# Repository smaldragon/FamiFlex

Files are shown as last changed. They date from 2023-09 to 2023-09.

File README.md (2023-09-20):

# FamiFlex

> Note: This project is currently in a prototype beta state, use at own risk

This is the repo for the FF1 (aka FamiFlex) famicom/famiclone homebrew mapper, more info is avaliable at:

https://smaldragon.github.io/blog/famiflex.html

Render of the PCB

* **kicad** - contains the original Kicad Files
* **python** - scripts to help with generating rom files for burning
* **gerbers** - `.zip` files for production with JLCPcb

## Changelog

### v0b

* Changed ROMS to smd PLCC sockets, to better fit cart shells
* Adjusted dimensions of PCB to better fit cart shells

### v0a

Initial Version

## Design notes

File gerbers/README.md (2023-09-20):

Pre-prepared .zip files ready for production via JLCPCB, for the best results choose the following options:

* 1.2mm PCB Thickness
+ ENIG surface finish
* Gold Fingers
* Specify a location for Order Number

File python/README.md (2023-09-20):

Hacky prototype python scripts for quickly converting a .nes file into binary files to write to ROM. Should generate the following:

* prg.65x - 512Kb file, holds PRG data
* chr.65x - 512Kb file, holds CHR data (only generated if the mapper uses CHR rom)

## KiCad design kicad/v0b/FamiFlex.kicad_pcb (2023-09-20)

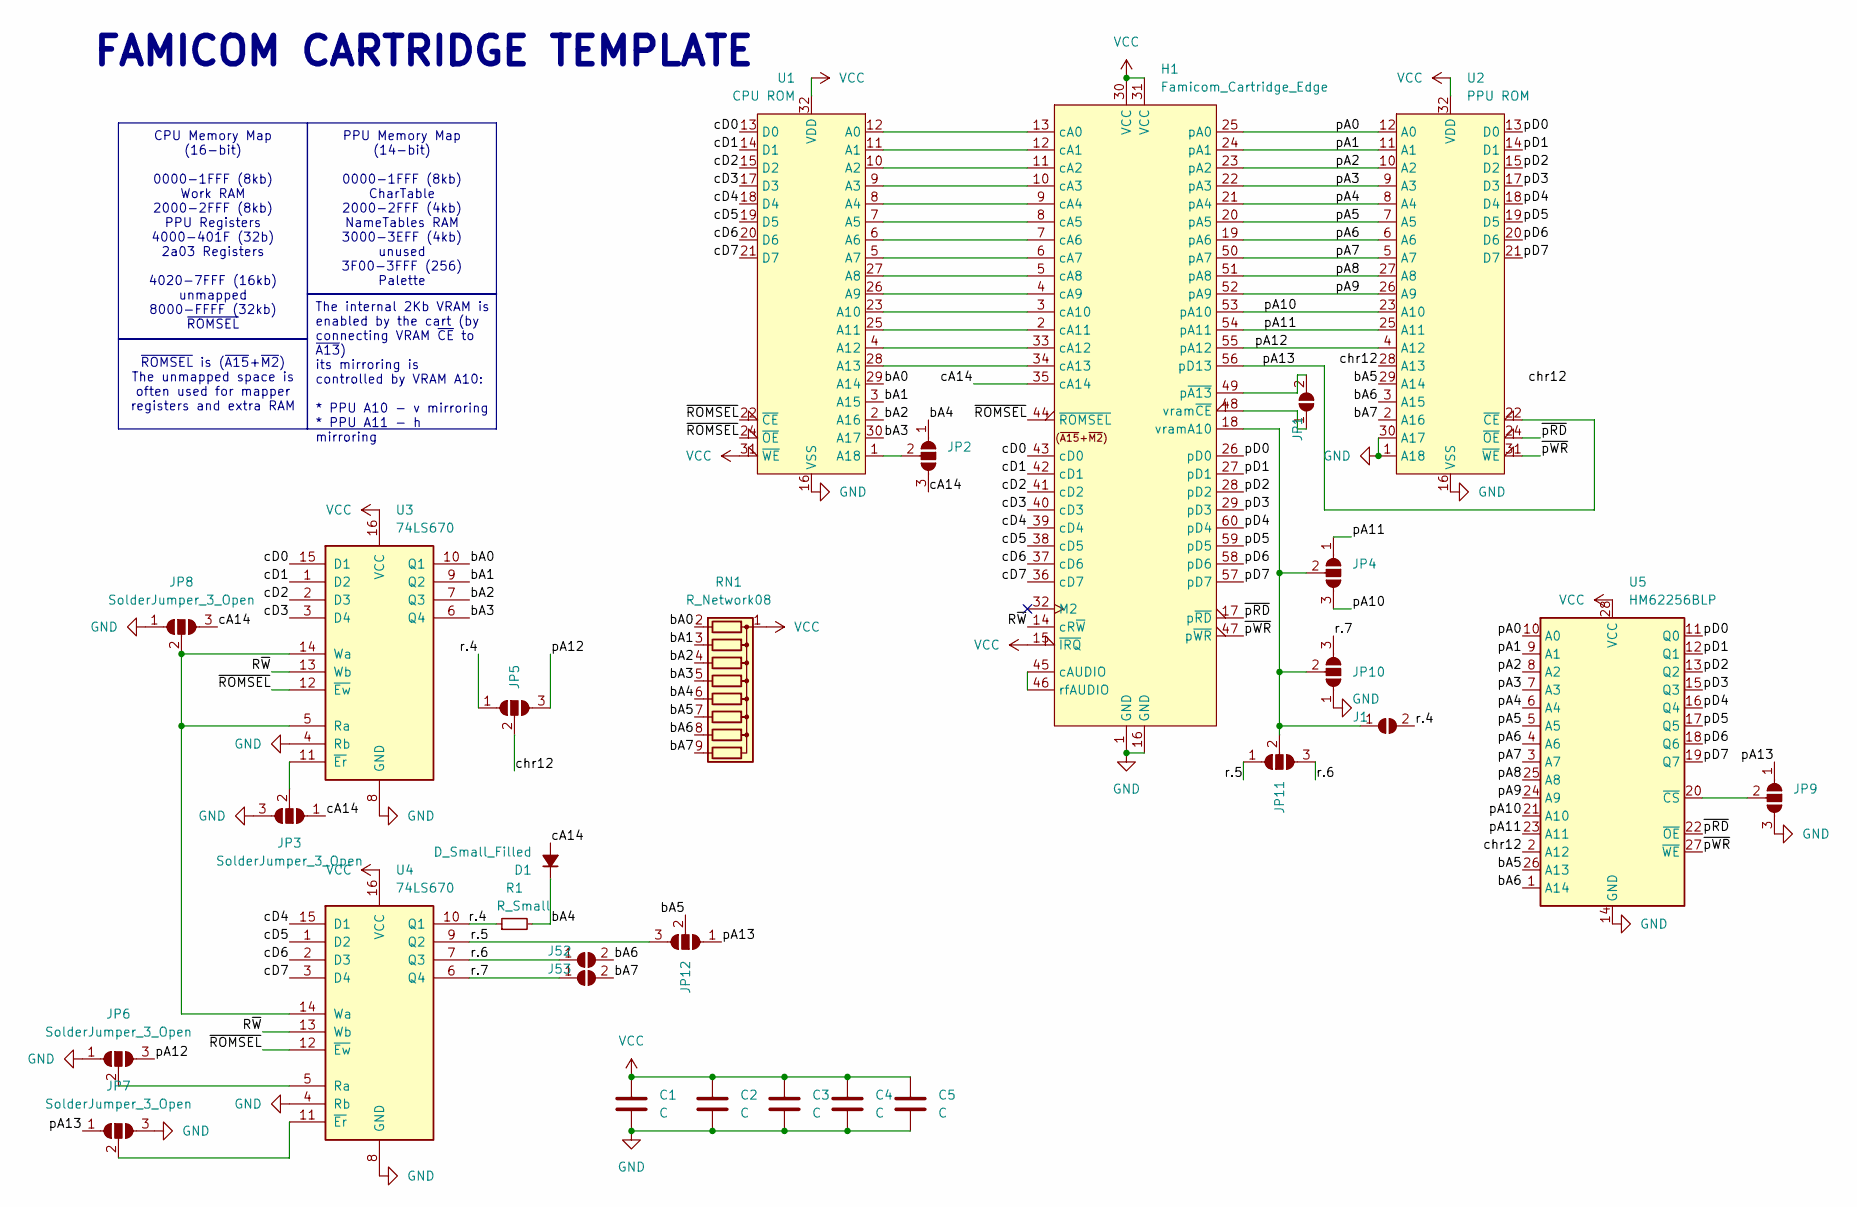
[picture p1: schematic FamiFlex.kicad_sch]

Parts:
C1, C2, C3, C4, C5: C; C_0805_2012Metric_Pad1.18x1.45mm_HandSolder
D1: D_Small_Filled; D_DO-41_SOD81_P2.54mm_Vertical_KathodeUp
H1: Famicom_Cartridge_Edge; Famicom Cartridge Edge Connector (long legs)
J1, J52, J53: SolderJumper_2_Open; SolderJumper-2_P1.3mm_Open_RoundedPad1.0x1.5mm
JP1: SolderJumper_2_Open; SolderJumper-2_P1.3mm_Open_RoundedPad1.0x1.5mm
JP2, JP3, JP4, JP5, JP6, JP7, JP8, JP9, JP10, JP11, JP12: SolderJumper_3_Open; SolderJumper-3_P1.3mm_Open_RoundedPad1.0x1.5mm
R1: R_Small; R_0805_2012Metric_Pad1.15x1.40mm_HandSolder
RN1: R_Network08; R_Array_SIP9
U1: CPU ROM; PLCC-32_SMD-Socket
U2: PPU ROM; PLCC-32_SMD-Socket
U3, U4: 74LS670; DIP-16_W7.62mm_Socket
U5: HM62256BLP; DIP-28_W15.24mm_Socket

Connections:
/R~W: H1.14 (cR~W), U3.13 (Wb), U4.13 (Wb)
/bA0: RN1.2 (R1), U1.29 (A14), U3.10 (Q1)
/bA1: RN1.3 (R2), U1.3 (A15), U3.9 (Q2)
/bA2: RN1.4 (R3), U1.2 (A16), U3.7 (Q3)
/bA3: RN1.5 (R4), U1.30 (A17), U3.6 (Q4)
/bA4: D1.1 (K), JP2.1 (A), R1.2, RN1.6 (R5)
/bA5: JP12.2 (C), RN1.7 (R6), U2.29 (A14), U5.26 (A13)
/bA6: J52.2 (B), RN1.8 (R7), U2.3 (A15), U5.1 (A14)
/bA7: J53.2 (B), RN1.9 (R8), U2.2 (A16)
/cA14: D1.2 (A), H1.35 (cA14), JP2.3 (B), JP3.1 (A), JP8.3 (B)
/cD0: H1.43 (cD0), U1.13 (D0), U3.15 (D1)
/cD1: H1.42 (cD1), U1.14 (D1), U3.1 (D2)
/cD2: H1.41 (cD2), U1.15 (D2), U3.2 (D3)
/cD3: H1.40 (cD3), U1.17 (D3), U3.3 (D4)
/cD4: H1.39 (cD4), U1.18 (D4), U4.15 (D1)
/cD5: H1.38 (cD5), U1.19 (D5), U4.1 (D2)
/cD6: H1.37 (cD6), U1.20 (D6), U4.2 (D3)
/cD7: H1.36 (cD7), U1.21 (D7), U4.3 (D4)
/chr12: JP5.2 (C), U2.28 (A13), U5.2 (A12)
/pA0: H1.25 (pA0), U2.12 (A0), U5.10 (A0)
/pA1: H1.24 (pA1), U2.11 (A1), U5.9 (A1)
/pA2: H1.23 (pA2), U2.10 (A2), U5.8 (A2)
/pA3: H1.22 (pA3), U2.9 (A3), U5.7 (A3)
/pA4: H1.21 (pA4), U2.8 (A4), U5.6 (A4)
/pA5: H1.20 (pA5), U2.7 (A5), U5.5 (A5)
/pA6: H1.19 (pA6), U2.6 (A6), U5.4 (A6)
/pA7: H1.50 (pA7), U2.5 (A7), U5.3 (A7)
/pA8: H1.51 (pA8), U2.27 (A8), U5.25 (A8)
/pA9: H1.52 (pA9), U2.26 (A9), U5.24 (A9)
/pA10: H1.53 (pA10), JP4.3 (B), U2.23 (A10), U5.21 (A10)
/pA11: H1.54 (pA11), JP4.1 (A), U2.25 (A11), U5.23 (A11)
/pA12: H1.55 (pA12), JP5.3 (B), JP6.3 (B), U2.4 (A12)
/pA13: H1.56 (pD13), JP7.1 (A), JP9.1 (A), JP12.1 (A), U2.22 (~CE)
/pD0: H1.26 (pD0), U2.13 (D0), U5.11 (Q0)
/pD1: H1.27 (pD1), U2.14 (D1), U5.12 (Q1)
/pD2: H1.28 (pD2), U2.15 (D2), U5.13 (Q2)
/pD3: H1.29 (pD3), U2.17 (D3), U5.15 (Q3)
/pD4: H1.60 (pD4), U2.18 (D4), U5.16 (Q4)
/pD5: H1.59 (pD5), U2.19 (D5), U5.17 (Q5)
/pD6: H1.58 (pD6), U2.20 (D6), U5.18 (Q6)
/pD7: H1.57 (pD7), U2.21 (D7), U5.19 (Q7)
/r.4: J1.2 (B), JP5.1 (A), R1.1, U4.10 (Q1)
/r.5: JP11.1 (A), JP12.3 (B), U4.9 (Q2)
/r.6: J52.1 (A), JP11.3 (B), U4.7 (Q3)
/r.7: J53.1 (A), JP10.3 (B), U4.6 (Q4)
/~ROMSEL: H1.44 (~ROMSEL), U1.22 (~CE), U1.24 (~OE), U3.12 (~Ew), U4.12 (~Ew)
/~pRD: H1.17 (p~RD), U2.24 (~OE), U5.22 (~OE)
/~pWR: H1.47 (p~WR), U2.31 (~WE), U5.27 (~WE)
GND: C1.2, C2.2, C3.2, C4.2, C5.2, H1.1 (GND), H1.16 (GND), JP3.3 (B), JP6.1 (A), JP7.3 (B), JP8.1 (A), JP9.3 (B), JP10.1 (A), U1.16 (VSS), U2.1 (A18), U2.16 (VSS), U2.30 (A17), U3.4 (Rb), U3.8 (GND), U4.4 (Rb), U4.8 (GND), U5.14 (GND)
unnamed: H1.13 (cA0), U1.12 (A0)
unnamed: H1.12 (cA1), U1.11 (A1)
unnamed: H1.11 (cA2), U1.10 (A2)
unnamed: H1.10 (cA3), U1.9 (A3)
unnamed: H1.9 (cA4), U1.8 (A4)
unnamed: H1.8 (cA5), U1.7 (A5)
unnamed: H1.7 (cA6), U1.6 (A6)
unnamed: H1.6 (cA7), U1.5 (A7)
unnamed: H1.5 (cA8), U1.27 (A8)
unnamed: H1.4 (cA9), U1.26 (A9)
unnamed: H1.3 (cA10), U1.23 (A10)
unnamed: H1.2 (cA11), U1.25 (A11)
unnamed: H1.33 (cA12), U1.4 (A12)
unnamed: H1.34 (cA13), U1.28 (A13)
unnamed: H1.45 (cAUDIO), H1.46 (rfAUDIO)
unnamed: H1.49 (p~A13), JP1.2 (B)
unnamed: H1.18 (vramA10), J1.1 (A), JP4.2 (C), JP10.2 (C), JP11.2 (C)
unnamed: H1.48 (vram~CE), JP1.1 (A)
unnamed: JP2.2 (C), U1.1 (A18)
unnamed: JP3.2 (C), U3.11 (~Er)
unnamed: JP6.2 (C), U4.5 (Ra)
unnamed: JP7.2 (C), U4.11 (~Er)
unnamed: JP8.2 (C), U3.5 (Ra), U3.14 (Wa), U4.14 (Wa)
unnamed: JP9.2 (C), U5.20 (~CS)
VCC: C1.1, C2.1, C3.1, C4.1, C5.1, H1.15 (~IRQ), H1.30 (VCC), H1.31 (VCC), RN1.1 (common), U1.31 (~WE), U1.32 (VDD), U2.32 (VDD), U3.16 (VCC), U4.16 (VCC), U5.28 (VCC)

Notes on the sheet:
PPU Memory Map (14-bit) 0000-1FFF (8kb) CharTable 2000-2FFF (4kb) NameTables RAM 3000-3EFF (4kb) unused 3F00-3FFF (256) Palette
CPU Memory Map (16-bit) 0000-1FFF (8kb) Work RAM 2000-2FFF (8kb) PPU Registers 4000-401F (32b) 2a03 Registers 4020-7FFF (16kb) unmapped 8000-FFFF (32kb) ~{ROMSEL}
~{ROMSEL} is (~{A15}+~{M2}) The unmapped space is often used for mapper registers and extra RAM
The internal 2Kb VRAM is enabled by the cart (by connecting VRAM ~{CE} to ~{A13}) its mirroring is controlled by VRAM A10: * PPU A10 - v mirroring * PPU A11 - h mirroring
FAMICOM CARTRIDGE TEMPLATE

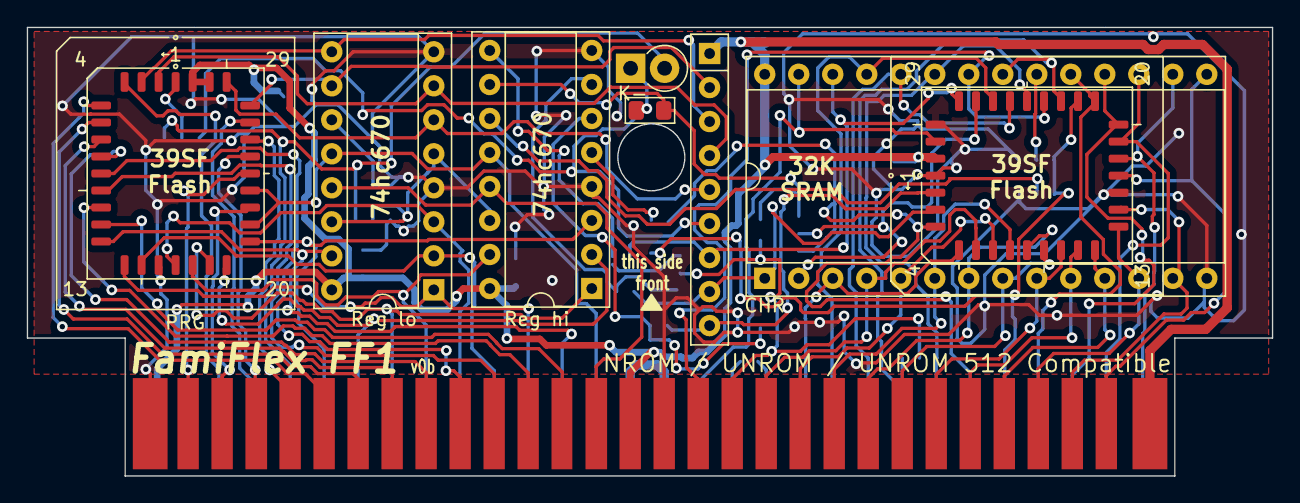
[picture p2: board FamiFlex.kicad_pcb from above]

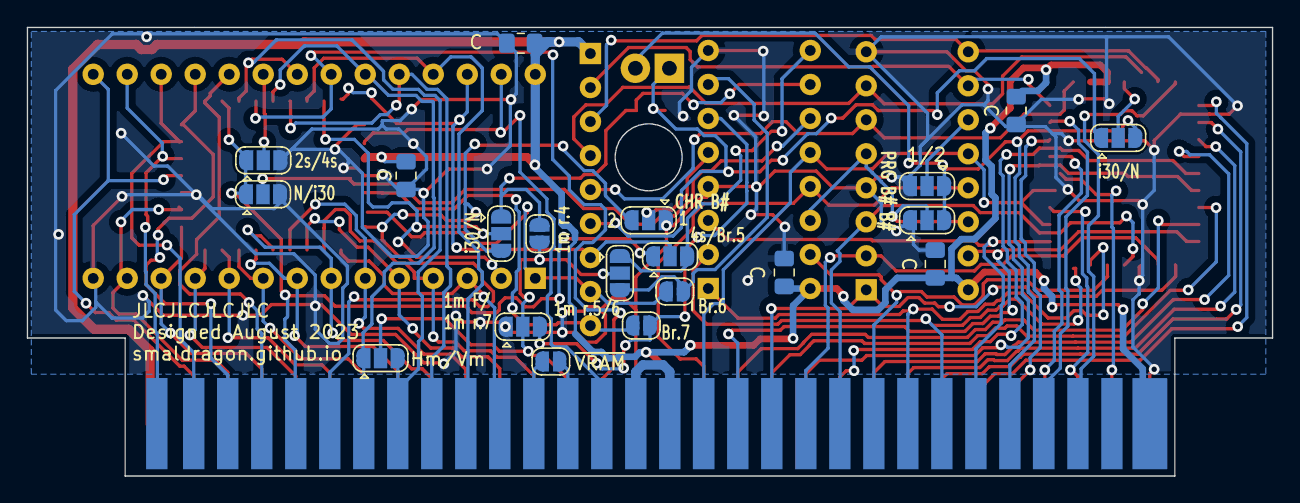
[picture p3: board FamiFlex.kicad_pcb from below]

Board: 2 copper layers, 93.0 x 33.5 mm, 29 parts (20 on the bottom side), 74 nets.
